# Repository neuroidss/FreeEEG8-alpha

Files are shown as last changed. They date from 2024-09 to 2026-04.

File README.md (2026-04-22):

# FreeEEG8-alpha

[mobile_diagnostic_stand](https://neuroidss.github.io/FreeEEG8-alpha/semantic_engine/mobile_diagnostic_stand.html)

[Neuro-Arena_Anonymous_Nodes](https://neuroidss.github.io/FreeEEG8-alpha/neuro_game/Neuro-Arena_Anonymous_Nodes.html)

[neuro_dungeon_gamepad_emulator_mimic](https://neuroidss.github.io/FreeEEG8-alpha/neuro_game/neuro_dungeon_gamepad_emulator_mimic.html)

[neuro_dungeon_gamepad_emulator_crystal](https://neuroidss.github.io/FreeEEG8-alpha/neuro_game/neuro_dungeon_gamepad_emulator_crystal.html)

[neuro_dungeon_gamepad_emulator_dash](https://neuroidss.github.io/FreeEEG8-alpha/neuro_game/neuro_dungeon_gamepad_emulator_dash.html)

[neuro_dungeon_gamepad_emulator_wm](https://neuroidss.github.io/FreeEEG8-alpha/neuro_game/neuro_dungeon_gamepad_emulator_wm.html)

[neuro_dungeon_gamepad_emulator_vr](https://neuroidss.github.io/FreeEEG8-alpha/neuro_game/neuro_dungeon_gamepad_emulator_vr.html)

[neuro_dungeon_emulator](https://neuroidss.github.io/FreeEEG8-alpha/neuro_game/neuro_dungeon_emulator.html)

[neuro_dungeon_dual_stick](https://neuroidss.github.io/FreeEEG8-alpha/neuro_game/neuro_dungeon_dual_stick.html)

[neuro_dungeon_cyber](https://neuroidss.github.io/FreeEEG8-alpha/neuro_game/neuro_dungeon_cyber.html)

[neuro_dungeon_joystick](https://neuroidss.github.io/FreeEEG8-alpha/neuro_game/neuro_dungeon_joystick.html)

[neuro_dungeon_4_wills](https://neuroidss.github.io/FreeEEG8-alpha/neuro_game/neuro_dungeon_4_wills.html)

[neuro_dungeon](https://neuroidss.github.io/FreeEEG8-alpha/neuro_game/neuro_dungeon.html)

[Emergent_Psytrance](https://neuroidss.github.io/FreeEEG8-alpha/psytrance/Emergent_Psytrance.html)

[Motor_Imagery_Web-Synth](https://neuroidss.github.io/FreeEEG8-alpha/psytrance/Motor_Imagery_Web-Synth.html)

[Neuro_Test_Bench](https://neuroidss.github.io/FreeEEG8-alpha/Neuro_Test_Bench/Neuro_Test_Bench.html)

[FreeEEG8-alpha_1_4_gerbers](https://github.com/neuroidss/FreeEEG8-alpha/releases/tag/FreeEEG8-alpha_1_4_gerbers)
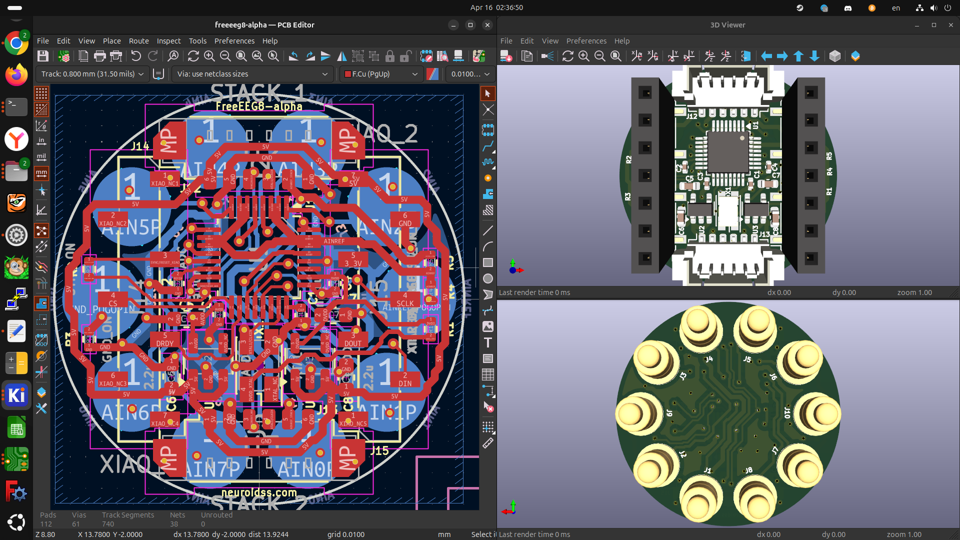
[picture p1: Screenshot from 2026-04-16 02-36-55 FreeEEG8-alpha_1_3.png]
freeeeg8-alpha1.4



run colab to get gerber&bom freeeeg8-alpha.kicad_pcb.zip

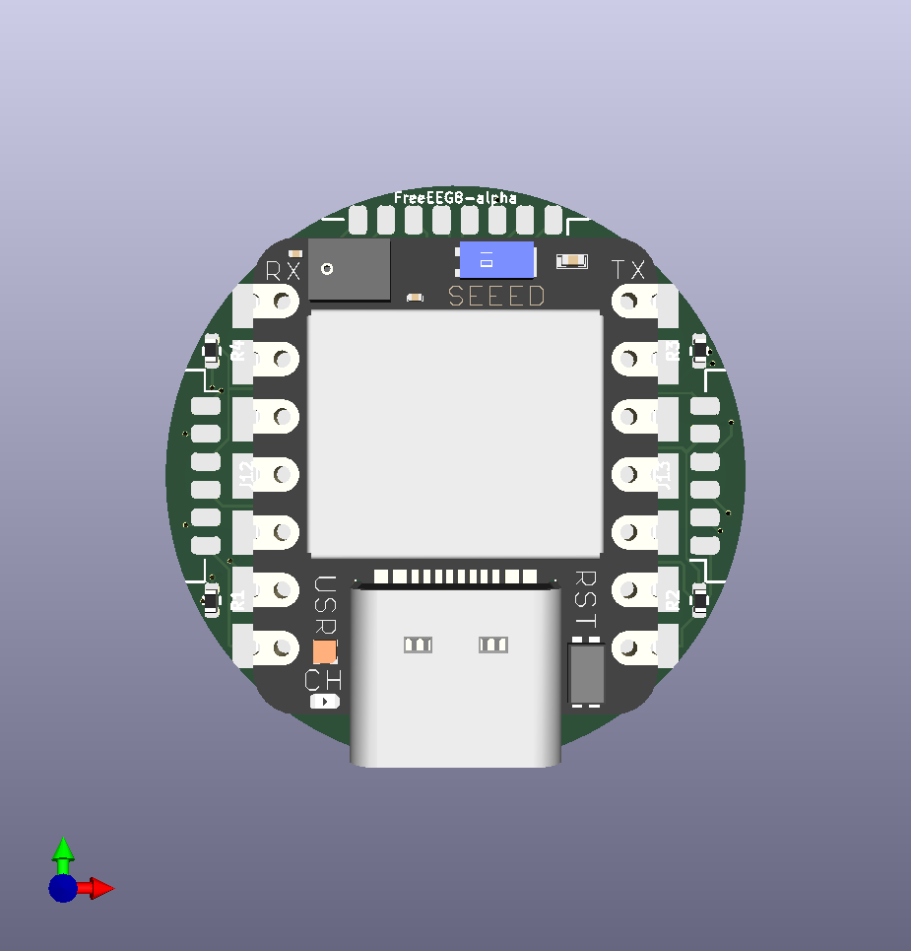
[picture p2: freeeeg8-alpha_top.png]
freeeeg8-alpha_top

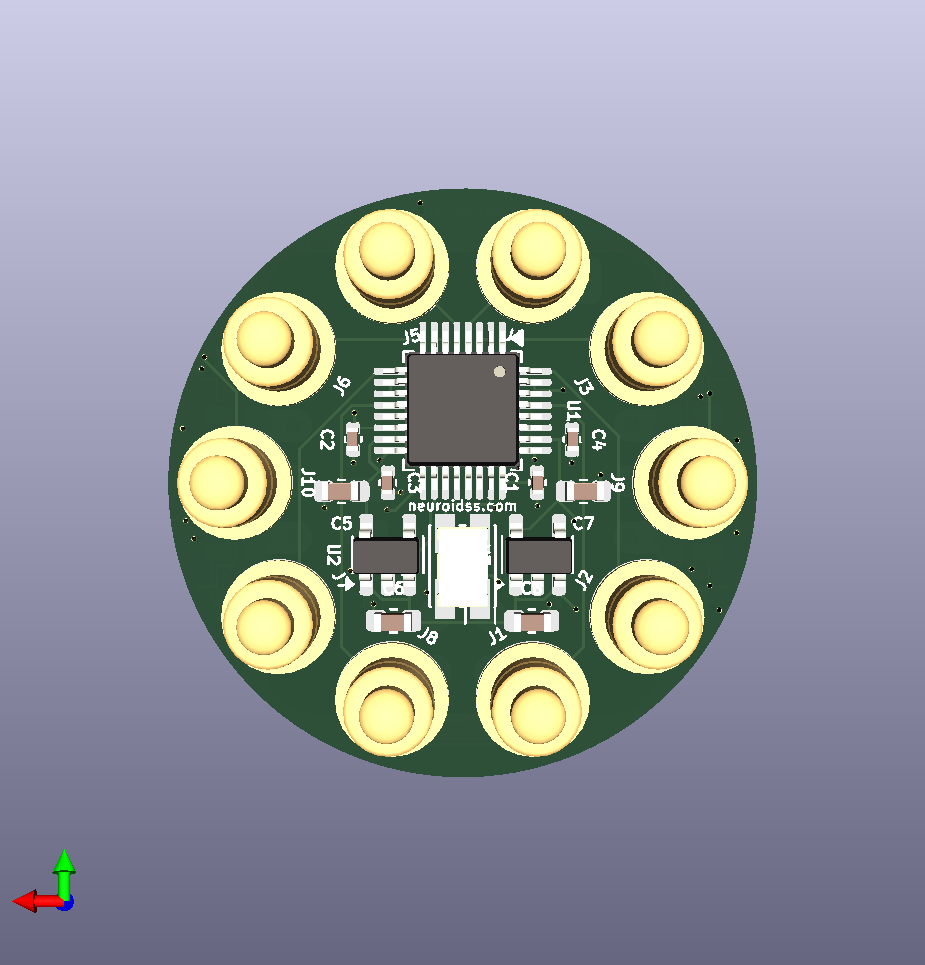
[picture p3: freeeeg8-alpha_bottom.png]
freeeeg8-alpha_bottom


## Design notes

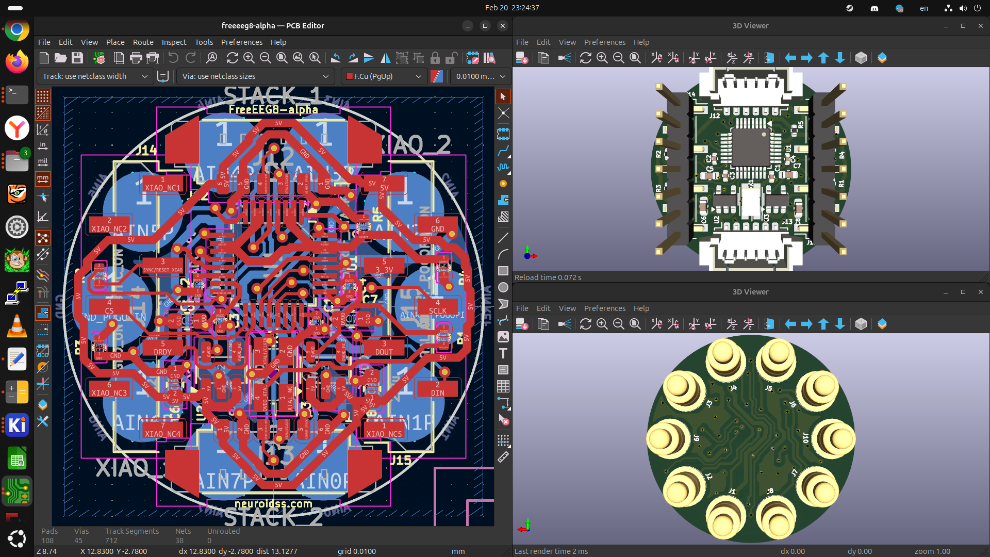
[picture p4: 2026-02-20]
Screenshot from 2026-02-20 23-24-41.png

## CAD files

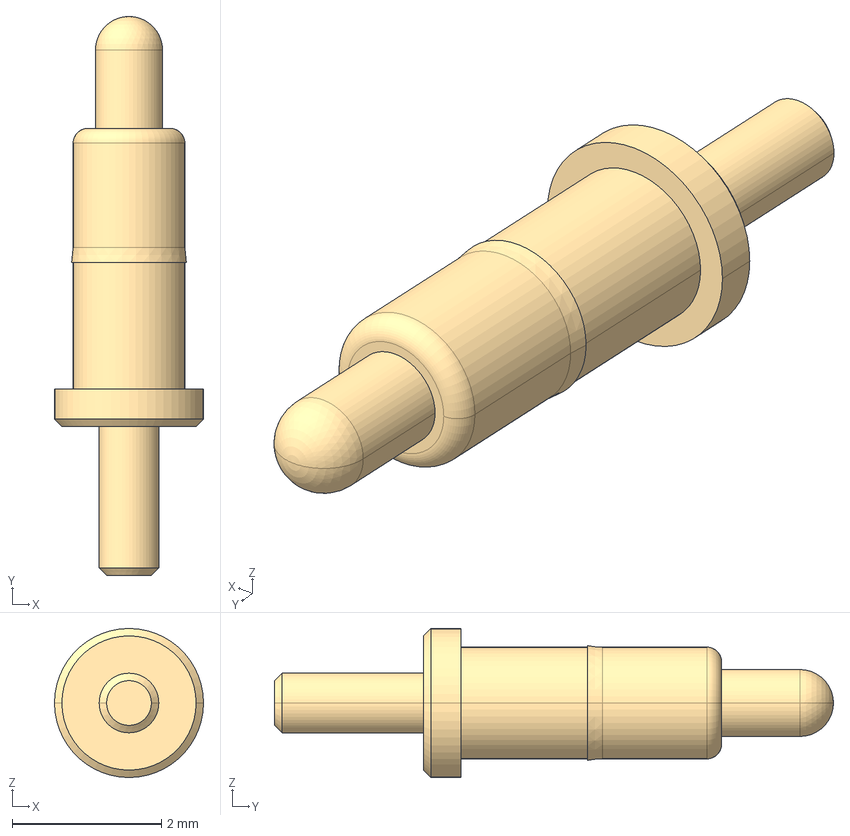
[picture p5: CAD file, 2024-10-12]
p70-2100045/p70-2100045.stp
2.00 x 7.50 x 2.00 mm

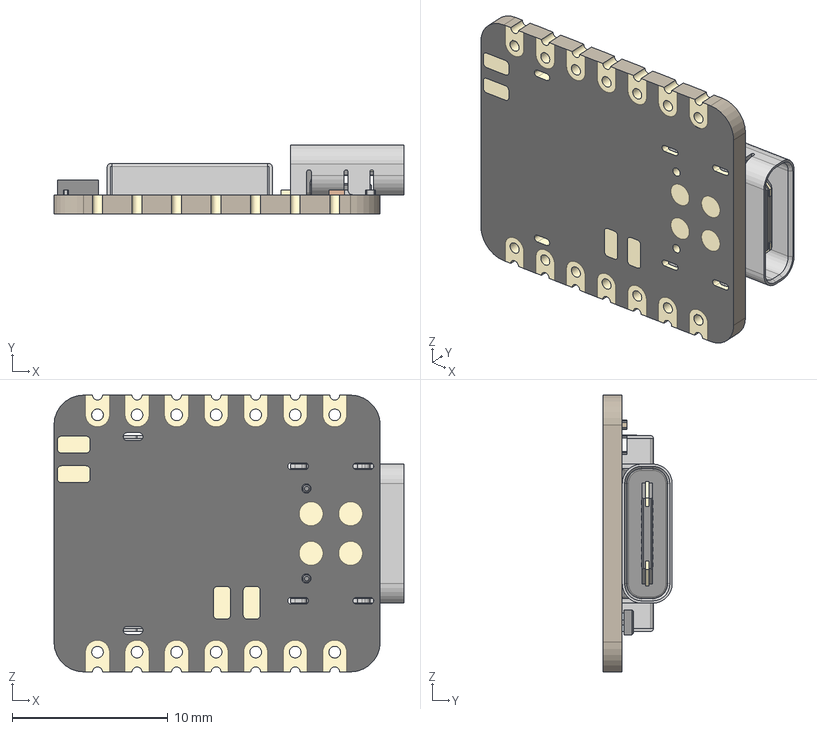
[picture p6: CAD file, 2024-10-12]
seeed-studio-xiao-nrf52840-3d-model/XIAO-nRF52840 v15.step
22.5 x 4.46 x 17.8 mm
BOSS-EXTRUDE14_8_
BOSS-EXTRUDE7_4_
BOSS-EXTRUDE7_3_
BOSS-EXTRUDE14_4_
BOSS-EXTRUDE14_2_
BOSS-EXTRUDE14_11_
BOSS-EXTRUDE7_7_
BOSS-EXTRUDE14_9_
BOSS-EXTRUDE14_3_
BOSS-EXTRUDE14_7_
MIRROR2
BOSS-EXTRUDE14_5_
BOSS-EXTRUDE14_12_
BOSS-EXTRUDE7_8_
BOSS-EXTRUDE7_1_
BOSS-EXTRUDE14_10_
BOSS-EXTRUDE7_9_
BOSS-EXTRUDE14_6_
BOSS-EXTRUDE14_1_
BOSS-EXTRUDE7_6_
BOSS-EXTRUDE7_2_
CUT-EXTRUDE5
BOSS-EXTRUDE7_5_
Shield
Pins
CAP x 2
ANT1
Silkscreen
CAP 3
LED
USR
2 v1

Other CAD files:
p70-2100045/p70-2100045.igs

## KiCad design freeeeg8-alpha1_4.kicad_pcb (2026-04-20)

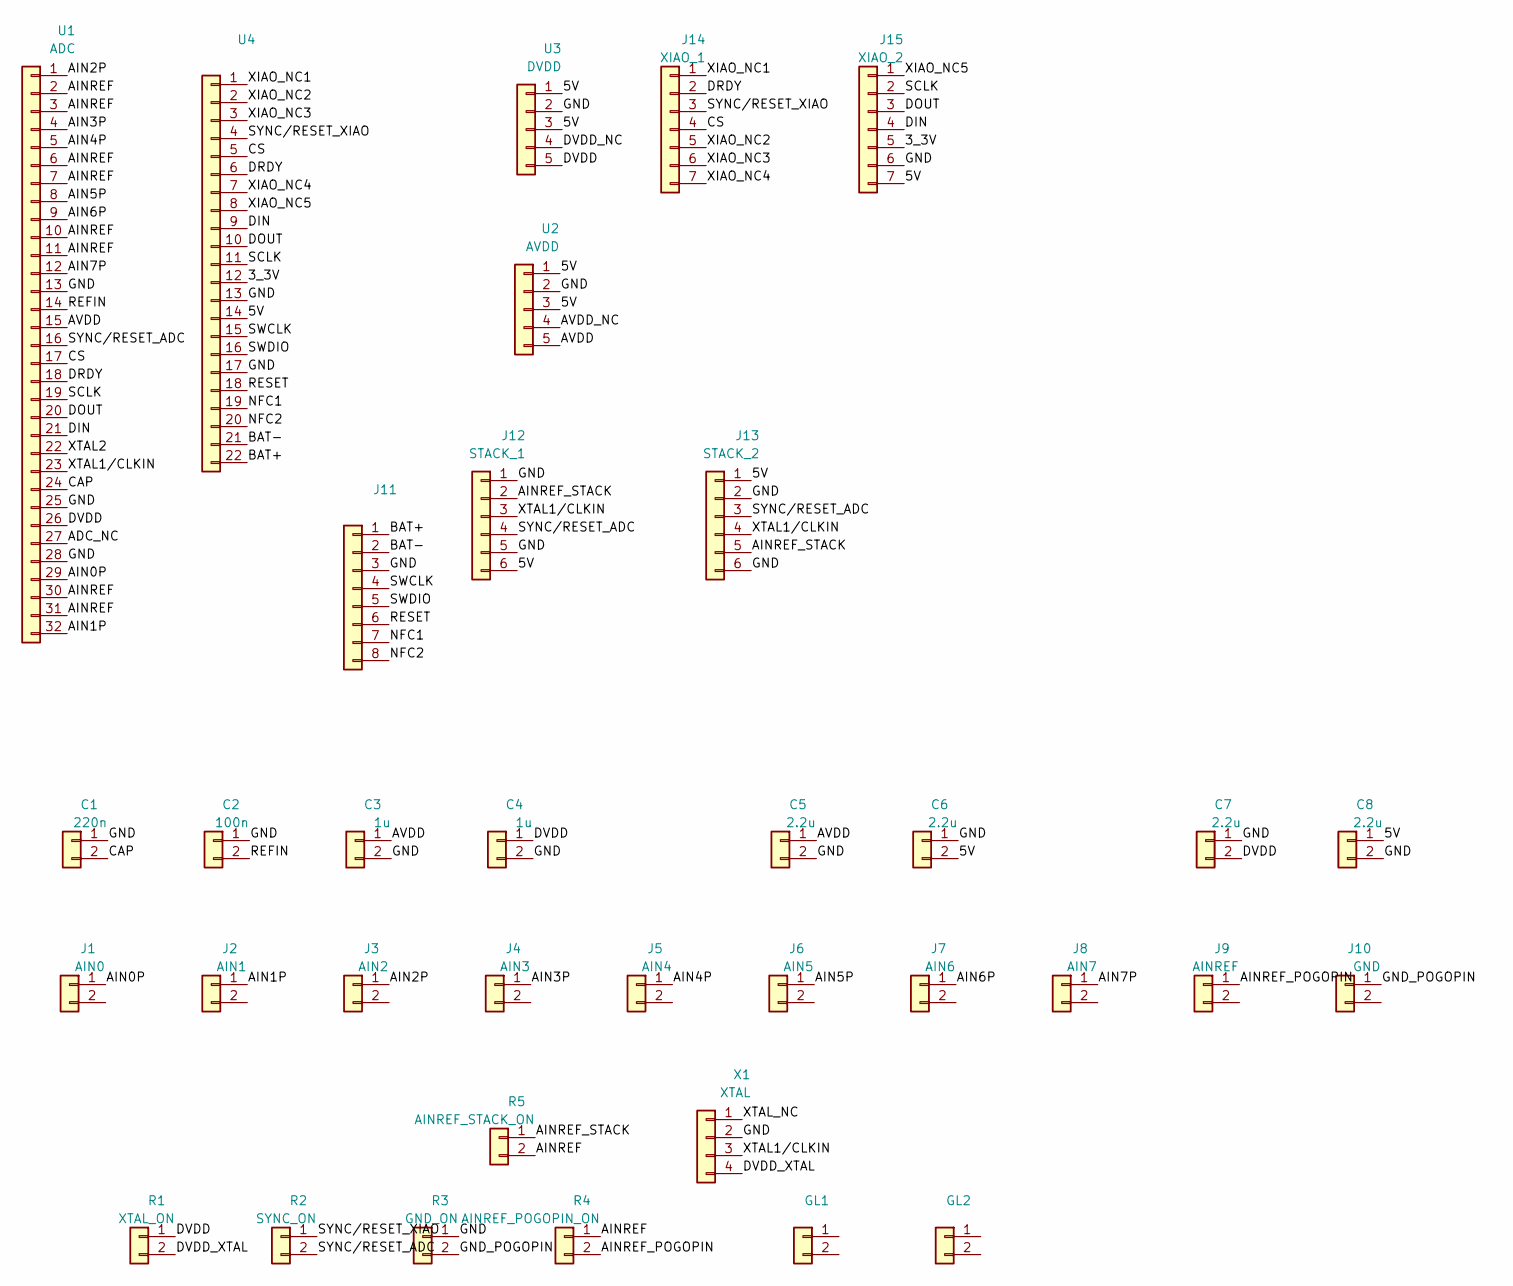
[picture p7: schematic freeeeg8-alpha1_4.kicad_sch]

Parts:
C1: 220n; C_0402_1005Metric; MPN CC0402KRX5R5BB224
C2: 100n; C_0402_1005Metric; MPN CL05B104KO5NNNC
C3, C4: 1u; C_0402_1005Metric; MPN CL05A105KO5NNNC
C5, C6, C7, C8: 2.2u; C_0603_1608Metric; MPN GRM188R71A225KE15D
GL1: FreeEEG8-alpha-title_5mm_SilkScreen
GL2: NeuroIDSS-url_5mm_SilkScreen
J1: AIN0; pogo_pin_d5x10mm_smd; MPN pogo-pin-d5x10mm-smd
J2: AIN1; pogo_pin_d5x10mm_smd; MPN pogo-pin-d5x10mm-smd
J3: AIN2; pogo_pin_d5x10mm_smd; MPN pogo-pin-d5x10mm-smd
J4: AIN3; pogo_pin_d5x10mm_smd; MPN pogo-pin-d5x10mm-smd
J5: AIN4; pogo_pin_d5x10mm_smd; MPN pogo-pin-d5x10mm-smd
J6: AIN5; pogo_pin_d5x10mm_smd; MPN pogo-pin-d5x10mm-smd
J7: AIN6; pogo_pin_d5x10mm_smd; MPN pogo-pin-d5x10mm-smd
J8: AIN7; pogo_pin_d5x10mm_smd; MPN pogo-pin-d5x10mm-smd
J9: AINREF; pogo_pin_d5x10mm_smd; MPN pogo-pin-d5x10mm-smd
J10: GND; pogo_pin_d5x10mm_smd; MPN pogo-pin-d5x10mm-smd
J11: Molex_PicoBlade_53398-0871_1x08-1MP_P1.25mm_Vertical_DNP
J12: STACK_1; Molex_PicoBlade_53398-0671_1x06-1MP_P1.25mm_Vertical_DNP; MPN 53398-0671
J13: STACK_2; Molex_PicoBlade_53398-0671_1x06-1MP_P1.25mm_Vertical_DNP; MPN 53398-0671
J14: XIAO_1; PinHeader_1x07_P2.54mm_Vertical_SMD_Pin1Right; MPN TSM-107-01-L-SV
J15: XIAO_2; PinHeader_1x07_P2.54mm_Vertical_SMD_Pin1Right; MPN TSM-107-01-L-SV
R1: XTAL_ON; R_0402_1005Metric; MPN RC0402JR-070RL
R2: SYNC_ON; R_0402_1005Metric; MPN RC0402JR-070RL
R3: GND_ON; R_0402_1005Metric; MPN RC0402JR-070RL
R4: AINREF_POGOPIN_ON; R_0402_1005Metric; MPN RC0402JR-070RL
R5: AINREF_STACK_ON; R_0402_1005Metric; MPN DNP
U1: ADC; LQFP-32_5x5mm_P0.5mm; MPN ADS131M08IPBSR
U2: AVDD; SOT-23-5; MPN LP5907QMFX-3.3Q1
U3: DVDD; SOT-23-5; MPN LP5907QMFX-3.3Q1
U4: XIAO-nRF52840-Sense-14P-2.54-21X17.8MM
X1: XTAL; Oscillator_SMD_EuroQuartz_XO32-4Pin_3.2x2.5mm_HandSoldering; MPN ECS-2520MVLC-081.92-CN-TR

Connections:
/3_3V: J15.5, U4.12
/5V: C6.2, C8.1, J12.6, J13.1, J15.7, U2.1, U2.3, U3.1, U3.3, U4.14
/ADC_NC: U1.27
/AIN0P: J1.1, U1.29
/AIN1P: J2.1, U1.32
/AIN2P: J3.1, U1.1
/AIN3P: J4.1, U1.4
/AIN4P: J5.1, U1.5
/AIN5P: J6.1, U1.8
/AIN6P: J7.1, U1.9
/AIN7P: J8.1, U1.12
/AINREF: R4.1, R5.2, U1.2, U1.3, U1.6, U1.7, U1.10, U1.11, U1.30, U1.31
/AINREF_POGOPIN: J9.1, R4.2
/AINREF_STACK: J12.2, J13.5, R5.1
/AVDD: C3.1, C5.1, U1.15, U2.5
/AVDD_NC: U2.4
/CAP: C1.2, U1.24
/CS: J14.4, U1.17, U4.5
/DIN: J15.4, U1.21, U4.9
/DOUT: J15.3, U1.20, U4.10
/DRDY: J14.2, U1.18, U4.6
/DVDD: C4.1, C7.2, R1.1, U1.26, U3.5
/DVDD_NC: U3.4
/DVDD_XTAL: R1.2, X1.4
/GND: C1.1, C2.1, C3.2, C4.2, C5.2, C6.1, C7.1, C8.2, J11.3, J12.1, J12.5, J13.2, J13.6, J15.6, R3.1, U1.13, U1.25, U1.28, U2.2, U3.2, U4.13, U4.17, X1.2
/GND_POGOPIN: J10.1, R3.2
/REFIN: C2.2, U1.14
/SCLK: J15.2, U1.19, U4.11
/SYNC/RESET_ADC: J12.4, J13.3, R2.2, U1.16
/SYNC/RESET_XIAO: J14.3, R2.1, U4.4
/XIAO_NC1: J14.1, U4.1
/XIAO_NC2: J14.5, U4.2
/XIAO_NC3: J14.6, U4.3
/XIAO_NC4: J14.7, U4.7
/XIAO_NC5: J15.1, U4.8
/XTAL1/CLKIN: J12.3, J13.4, U1.23, X1.3
/XTAL2: U1.22
/XTAL_NC: X1.1
unnamed: J11.1, U4.22
unnamed: J11.2, U4.21
unnamed: J11.4, U4.15
unnamed: J11.5, U4.16
unnamed: J11.6, U4.18
unnamed: J11.7, U4.19
unnamed: J11.8, U4.20

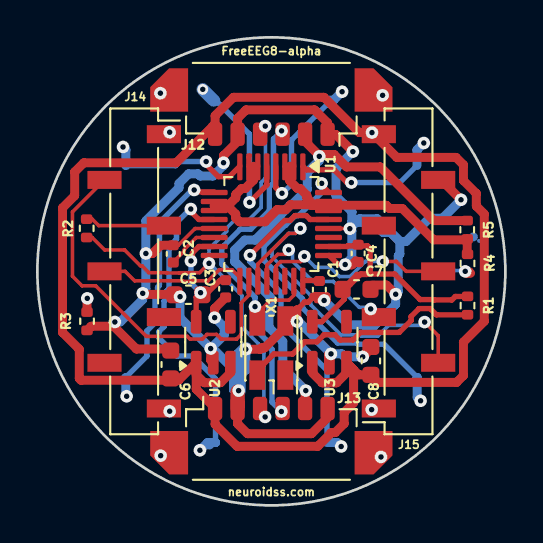
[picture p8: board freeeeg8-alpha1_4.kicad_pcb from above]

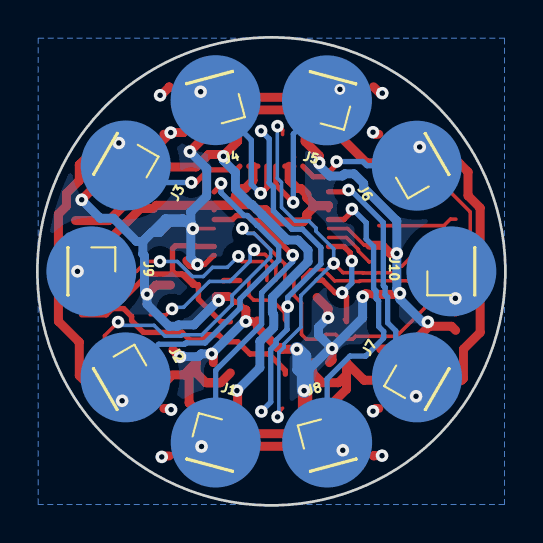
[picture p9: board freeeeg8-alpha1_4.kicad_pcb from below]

Board: 2 copper layers, 26.0 x 26.0 mm, 33 parts (10 on the bottom side), 27 nets.

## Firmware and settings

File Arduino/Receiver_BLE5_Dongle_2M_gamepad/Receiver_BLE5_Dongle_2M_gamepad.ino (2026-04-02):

#include <Arduino.h>
#include <NimBLEDevice.h>
#include "USB.h"
#include "USBHIDGamepad.h"
#include <algorithm>

// ===================== НАСТРОЙКИ =====================
#define SERVICE_UUID        "4fafc201-1fb5-459e-8fcc-c5c9c331914b"
#define CHARACTERISTIC_UUID "beb5483e-36e1-4688-b7f5-ea07361b26a8"

#define CH_COUNT 8
#define BUF_SIZE 256

const float UV_SCALE = (1.2f / 4.0f / 8388607.0f) * 1000000.0f;
const float RADIUS = 10.0f;
const float ANGLES[8] = {-72, -36, 36, 72, 108, 144, -144, -108};

float EX[8], EY[8];

// === ПАРАМЕТРЫ СТАБИЛЬНОСТИ (подкручивай здесь) ===
float SKILL_LEVEL = 0.05f;     // 0.08–0.12 — самый комфортный диапазон
float STICK_GAIN   = 3.0f;     // 2.0 = очень чувствительно, 3.0 = спокойнее

// =====================================================

volatile int eeg_head = 0;
float eeg[CH_COUNT][BUF_SIZE];

float re[CH_COUNT][BUF_SIZE];
float im[CH_COUNT][BUF_SIZE];
float centered[CH_COUNT][BUF_SIZE];

float norm_re[CH_COUNT][37];
float norm_im[CH_COUNT][37];

float cX = 0, cY = 0, cTQ = 0, persistence = 0;
float lastTX = 0, lastTY = 0;

volatile bool dataReady = false;

USBHIDGamepad Gamepad;

unsigned long lastDebug = 0;
int processCounter = 0;

// ===================== БЫСТРЫЙ FFT =====================
void fft(float* vR, float* vI) {
    int n = BUF_SIZE;
    for (int i = 0, j = 0; i < n; i++) {
        if (j > i) { std::swap(vR[i], vR[j]); std::swap(vI[i], vI[j]); }
        int m = n >> 1; while (m >= 1 && j >= m) { j -= m; m >>= 1; } j += m;
    }
    for (int s = 2; s <= n; s <<= 1) {
        int m = s >> 1; float t = -2.0f * PI / s;
        float wr = cosf(t), wi = sinf(t);
        for (int b = 0; b < n; b += s) {
            float ar = 1, ai = 0;
            for (int j = 0; j < m; j++) {
                int u = b + j, v = u + m;
                float tr = ar * vR[v] - ai * vI[v];
                float ti = ar * vI[v] + ai * vR[v];
                vR[v] = vR[u] - tr; vI[v] = vI[u] - ti;
                vR[u] += tr; vI[u] += ti;
                float nr = ar * wr - ai * wi; ai = ar * wi + ai * wr; ar = nr;
            }
        }
    }
}

// ===================== ciPLV =====================
float get_ciPLV(int a, int b) {
    float sr = 0, si = 0;
    for (int k = 18; k <= 36; k++) {
        float uAr = norm_re[a][k], uAi = norm_im[a][k];
        float uBr = norm_re[b][k], uBi = norm_im[b][k];
        sr += (uAr * uBr + uAi * uBi);
        si += (uAi * uBr - uAr * uBi);
    }
    float mRe = sr / 19.0f;
    float mIm = si / 19.0f;
    float den = sqrtf(fmaxf(0.0f, 1.0f - mRe * mRe));
    return (den < 0.001f) ? 0.0f : mIm / den;
}

// ===================== ОСНОВНАЯ НЕЙРО-ОБРАБОТКА =====================
void processNeuro() {
    int current_head = eeg_head;

    // 1. CAR + FFT
    for (int c = 0; c < CH_COUNT; c++) {
        float sum = 0;
        for (int t = 0; t < BUF_SIZE; t++) {
            int idx = (current_head + t) % BUF_SIZE;
            centered[c][t] = eeg[c][idx];
            sum += centered[c][t];
        }
        float avg = sum / BUF_SIZE;
        for (int t = 0; t < BUF_SIZE; t++) {
            re[c][t] = centered[c][t] - avg;
            im[c][t] = 0.0f;
        }
        fft(re[c], im[c]);

        // Notch 50/100 Hz
        for (int k : {51, 102}) {
            for (int i = -1; i <= 1; i++) {
                if (k + i >= 0 && k + i < BUF_SIZE) re[c][k + i] = im[c][k + i] = 0.0f;
            }
        }
    }

    // 2. Нормализация
    for (int c = 0; c < CH_COUNT; c++) {
        for (int k = 18; k <= 36; k++) {
            float mag = sqrtf(re[c][k]*re[c][k] + im[c][k]*im[c][k]) + 1e-6f;
            norm_re[c][k] = re[c][k] / mag;
            norm_im[c][k] = im[c][k] / mag;
        }
    }

    // 3. Tensor + ciPLV
    float tx = 0, ty = 0, tq = 0, div = 0;
    for (int i = 0; i < CH_COUNT; i++) {
        for (int j = i + 1; j < CH_COUNT; j++) {
            float v = get_ciPLV(i, j);
            float dx = EX[j] - EX[i], dy = EY[j] - EY[i];
            tx += v * dx; ty += v * dy;
            tq += (v * (EX[i] * dy - EY[i] * dx)) * 0.01f;
            div += v * (dx * EX[i] + dy * EY[i]) / RADIUS;
        }
    }

    // 4. Persistence (медленнее затухает)
    float mag = sqrtf(tx*tx + ty*ty) + 1e-6f;
    float cosTheta = (tx*lastTX + ty*lastTY) / (mag * sqrtf(lastTX*lastTX + lastTY*lastTY) + 1e-6f);
    if (mag > 0.05f && cosTheta > 0.8f) persistence = fminf(1.0f, persistence + 0.05f);
    else persistence *= 0.97f;
    lastTX = tx; lastTY = ty;

    // 5. Физика — максимально плавная
    float sm = 0.985f - (SKILL_LEVEL * 0.05f);
    cX = cX * sm + tx * (SKILL_LEVEL * 1.5f) * (1.0f - sm);
    cY = cY * sm + ty * (SKILL_LEVEL * 1.5f) * (1.0f - sm);
    cTQ = cTQ * sm + tq * (SKILL_LEVEL * 0.75f) * (1.0f - sm);

    float b = 1.0f + persistence * 6.0f;

    int8_t lx = constrain((cX * b / STICK_GAIN) * 127.0f, -127, 127);
    int8_t ly = constrain((-cY * b / STICK_GAIN) * 127.0f, -127, 127);
    int8_t rtq_val = constrain((cTQ * b / STICK_GAIN) * 127.0f, -127, 127);

    Gamepad.leftStick(lx, ly);
    Gamepad.rightStick(rtq_val, 0);

    bool atk   = (div < -1.8f) && (persistence > 0.3f);
    bool inter = (div >  1.8f) && (persistence > 0.3f);

    if (atk)   Gamepad.pressButton(2);   else Gamepad.releaseButton(2);
    if (inter) Gamepad.pressButton(1);   else Gamepad.releaseButton(1);

    // === ДЕБАГ (раз в секунду) ===
    processCounter++;
    if (millis() - lastDebug > 1000) {
        Serial.printf("cX=%.2f  cY=%.2f  cTQ=%.2f  pers=%.2f  div=%.2f  SKILL=%.2f\n",
                      cX, cY, cTQ, persistence, div, SKILL_LEVEL);
        lastDebug = millis();
        processCounter = 0;
    }

    yield();
}

// ===================== BLE CALLBACK =====================
void notifyCallback(NimBLERemoteCharacteristic* pRemoteCharacteristic, uint8_t* pData, size_t length, bool isNotify) {
    if (length >= 33 && pData[0] == 0xA0) {
        for (int i = 0; i < CH_COUNT; i++) {
            int s = 2 + i * 3;
            int32_t v = (pData[s] << 16) | (pData[s + 1] << 8) | pData[s + 2];
            if (v & 0x800000) v -= 0x1000000;
            eeg[i][eeg_head] = (float)v * UV_SCALE;
        }
        eeg_head = (eeg_head + 1) % BUF_SIZE;
        dataReady = true;
    }
}

NimBLEClient* pClient = nullptr;
NimBLEAdvertisedDevice* targetDevice = nullptr;
bool doConnect = false;

class ClientCallbacks : public NimBLEClientCallbacks {
    void onConnect(NimBLEClient* pClient) override { 
        pClient->updatePhy(BLE_HCI_LE_PHY_2M_PREF_MASK, BLE_HCI_LE_PHY_2M_PREF_MASK);
    }
    void onDisconnect(NimBLEClient* pClient, int reason) override { 
        NimBLEDevice::getScan()->start(0, false);
    }
};

class ScanCallbacks : public NimBLEScanCallbacks {
    void onResult(const NimBLEAdvertisedDevice* advDevice) override {
        if (advDevice->isAdvertisingService(NimBLEUUID(SERVICE_UUID))) {
            targetDevice = new NimBLEAdvertisedDevice(*advDevice);
            doConnect = true;
            NimBLEDevice::getScan()->stop();
        }
    }
};

// ===================== SETUP & LOOP =====================
void setup() {
    Serial.begin(921600);

    for (int i = 0; i < 8; i++) {
        float a = ANGLES[i] * PI / 180.0f;
        EX[i] = cosf(a) * RADIUS;
        EY[i] = sinf(a) * RADIUS;
    }

    Gamepad.begin();
    USB.VID(0x045E);
    USB.PID(0x028E);
    USB.begin();

    // Маленький клик при старте (как в Python)
    Gamepad.pressButton(0);
    delay(80);
    Gamepad.releaseButton(0);

    NimBLEDevice::init("FreeEEG_Dongle");
    NimBLEDevice::setPower(ESP_PWR_LVL_P3);
    NimBLEDevice::setMTU(256);

    NimBLEScan* pScan = NimBLEDevice::getScan();
    pScan->setScanCallbacks(new ScanCallbacks());
    pScan->start(0, false);
}

void loop() {
    if (doConnect) {
        doConnect = false;
        pClient = NimBLEDevice::createClient();
        pClient->setClientCallbacks(new ClientCallbacks(), false);
        if (pClient->connect(targetDevice)) {
            NimBLERemoteService* pSvc = pClient->getService(SERVICE_UUID);
            if (pSvc) {
                NimBLERemoteCharacteristic* pChr = pSvc->getCharacteristic(CHARACTERISTIC_UUID);
                if (pChr) pChr->subscribe(true, notifyCallback);
            }
        }
        delete targetDevice;
        targetDevice = nullptr;
    }

    if (dataReady) {
        dataReady = false;
        static int throttle = 0;
        if (++throttle >= 4) {        // ~62 Гц — плавнее чем раньше
            processNeuro();
            throttle = 0;
        }
    }
}

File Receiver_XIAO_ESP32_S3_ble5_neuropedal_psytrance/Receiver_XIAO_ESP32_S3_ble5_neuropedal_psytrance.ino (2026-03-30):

#include <Arduino.h>
#include <driver/i2s.h>
#include <NimBLEDevice.h>
#include <math.h>
#include "esp_dsp.h" // Библиотека для аппаратного FFT

// ==========================================
// ПИНЫ АУДИО (Твои пины для XIAO ESP32-S3)
// ==========================================
#define I2S_BCLK       D5
#define I2S_LRCK       D4
#define I2S_MCLK       D8 // Опционально, если кодек требует Master Clock
#define I2S_DIN        D3 // Вход с АЦП (Гитара)
#define I2S_DOUT       D2 // Выход на ЦАП (На комбик)

#define SAMPLE_RATE    44100
#define BUFFER_SIZE    128 // Уменьшаем для меньшей задержки

// ==========================================
// BLE НАСТРОЙКИ
// ==========================================
#define SERVICE_UUID        "4fafc201-1fb5-459e-8fcc-c5c9c331914b"
#define CHARACTERISTIC_UUID "beb5483e-36e1-4688-b7f5-ea07361b26a8"

// === ГЛОБАЛЬНЫЕ ПЕРЕМЕННЫЕ (для обмена между ядрами) ===
volatile bool is_connected = false;
volatile unsigned long last_packet_time = 0;

// Структура для нейро-параметров (заполняется на Ядре 0, читается на Ядре 1)
struct NeuroParams {
    float deltaAmp, thetaAmp, alphaAmp, gammaAmp;
    float leadX, leadY;
    // Упрощенные фазы для триггеров (0.0 -> 1.0)
    float deltaPhase, thetaPhase; 
};
volatile NeuroParams neuroParams;

// Структура для параметров инструмента (заполняется на Ядре 1, читается на Ядре 1)
struct InstrumentParams {
    float rhythm;   // Сила удара (0.0 - 1.0)
    float tonality; // Высота тона/спектр (0.0 - 1.0)
};
volatile InstrumentParams instrumentParams;

// === ГЕОМЕТРИЯ СЕНСОРА (Твоя, шаг 36 градусов) ===
const float COS_TABLE[8] = { 0.809, 0.309, -0.309, -0.809, -0.809, -0.309, 0.309, 0.809 };
const float SIN_TABLE[8] = { 0.588, 0.951, 0.951, 0.588, -0.588, -0.951, -0.951, -0.588 };

// ==========================================
// DSP: ЭЭГ ОБРАБОТКА (IIR-ФИЛЬТРЫ) - ЯДРО 0
// ==========================================
// Biquad фильтры (pre-calculated for 250Hz sample rate)
float b_delta[3] = {0.0025, 0, -0.0025}; float a_delta[3] = {1, -1.99, 0.99};
float b_theta[3] = {0.014, 0, -0.014};  float a_theta[3] = {1, -1.97, 0.97};
float b_alpha[3] = {0.02, 0, -0.02};    float a_alpha[3] = {1, -1.90, 0.95};
float b_gamma[3] = {0.1, 0, -0.1};      float a_gamma[3] = {1, -1.17, 0.80};

// Состояния фильтров
float z_delta[8][2] = {0}, z_theta[8][2] = {0}, z_alpha[8][2] = {0}, z_gamma[8][2] = {0};
float prev_delta_val = 0, prev_theta_val = 0;

void processEEGPacket(const uint8_t* pkt) {
    float raw[8], mean = 0;
    for(int i=0; i<8; i++) {
        int32_t v = (pkt[2+i*3]<<16) | (pkt[3+i*3]<<8) | pkt[4+i*3];
        if(v & 0x800000) v -= 0x1000000;
        raw[i] = (float)v * ((1.2 / 32.0 / 8388607.0) * 1e6);
        mean += raw[i];
    }
    mean /= 8.0;

    float global_signal = 0;
    float vx = 0, vy = 0;
    for(int i=0; i<8; i++) {
        global_signal += raw[i];
        const float centered = raw[i] - mean;
        vx += centered * COS_TABLE[i];
        vy += centered * SIN_TABLE[i];
    }
    global_signal /= 8.0;
    
    // Фильтрация и вычисление амплитуд
    float delta_out=0, theta_out=0, alpha_out=0, gamma_out=0;
    
    // IIR Biquad filter implementation (Direct Form I)
    auto filter_channel = [&](float input, float b[], float a[], float z[]) {
        float out = b[0] * input + z[0];
        z[0] = b[1] * input - a[1] * out + z[1];
        z[1] = b[2] * input - a[2] * out;
        return out;
    };
    
    // Delta and Theta use global signal
    delta_out = filter_channel(global_signal, b_delta, a_delta, z_delta[0]);
    theta_out = filter_channel(global_signal, b_theta, a_theta, z_theta[0]);

    // Alpha and Gamma average over channels
    float alpha_sum = 0, gamma_sum = 0;
    for(int i=0; i<8; i++) {
        alpha_sum += abs(filter_channel(raw[i] - mean, b_alpha, a_alpha, z_alpha[i]));
        gamma_sum += abs(filter_channel(raw[i] - mean, b_gamma, a_gamma, z_gamma[i]));
    }
    alpha_out = alpha_sum / 8.0;
    gamma_out = gamma_sum / 8.0;

    // Сглаживание амплитуд (Envelope Follower)
    neuroParams.deltaAmp = neuroParams.deltaAmp * 0.9 + abs(delta_out) * 0.1 * 5.0;
    neuroParams.thetaAmp = neuroParams.thetaAmp * 0.9 + abs(theta_out) * 0.1 * 3.0;
    neuroParams.alphaAmp = neuroParams.alphaAmp * 0.9 + alpha_out * 0.1 * 2.0;
    neuroParams.gammaAmp = neuroParams.gammaAmp * 0.9 + gamma_out * 0.1 * 1.5;

    // Сглаживание вектора
    neuroParams.leadX = neuroParams.leadX * 0.95 + vx * 0.05;
    neuroParams.leadY = neuroParams.leadY * 0.95 + vy * 0.05;
    
    // Упрощенные триггеры фазы через пересечение нуля
    if(delta_out > 0 && prev_delta_val <= 0) neuroParams.deltaPhase = 1.0; else neuroParams.deltaPhase *= 0.9;
    if(theta_out > 1.57 && prev_theta_val <= 1.57) neuroParams.thetaPhase = 1.0; else neuroParams.thetaPhase *= 0.9;
    prev_delta_val = delta_out;
    prev_theta_val = theta_out;
}

// ==========================================
// BLE КОЛЛБЭКИ И ЗАДАЧА (ЯДРО 0)
// ==========================================
void notifyCallback(NimBLERemoteCharacteristic* pChr, uint8_t* pData, size_t length, bool isNotify) {
    // Просто перекидываем данные в буфер
    // Парсинг будет происходить в основном цикле задачи, чтобы не блокировать BLE
}

class ClientCallbacks : public NimBLEClientCallbacks {
    void onConnect(NimBLEClient* pClient) { is_connected = true; }
    void onDisconnect(NimBLEClient* pClient, int reason) { 
        is_connected = false;
        NimBLEDevice::getScan()->start(0, false);
    }
};

class ScanCallbacks : public NimBLEScanCallbacks {
    void onResult(const NimBLEAdvertisedDevice* advertisedDevice) {
        if (advertisedDevice->isAdvertisingService(NimBLEUUID(SERVICE_UUID))) {
            NimBLEDevice::getScan()->stop();
            NimBLEDevice::createClient()->connect(advertisedDevice);
        }
    }
};

void bleTask(void *pvParameters) {
    NimBLEDevice::init("ESP32-NeuroSynth");
    NimBLEClient* pClient = NimBLEDevice::createClient();
    pClient->setClientCallbacks(new ClientCallbacks());

    NimBLEScan* pScan = NimBLEDevice::getScan();
    pScan->setScanCallbacks(new ScanCallbacks());
    pScan->setActiveScan(true);
    pScan->start(0, false);

    while(1) {
        if(is_connected) {
             // Здесь можно добавить логику переподключения или проверки связи
            if(millis() - last_packet_time > 1000) {
                is_connected = false;
                pClient->disconnect();
            }
        }
        vTaskDelay(100 / portTICK_PERIOD_MS);
    }
}
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
